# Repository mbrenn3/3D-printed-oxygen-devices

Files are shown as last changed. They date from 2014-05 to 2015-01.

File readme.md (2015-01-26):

This folder contains all the documentation, protocols, data, and manuscript for the 3D printed oxygen devices. 

This will be my first attempt at git tracking a master folder with all the files in one folder.

Inbox
---

- [ ] make a github pages for project to coincide with publication
- [ ] check plos one format and latex outline

todo
====
- [ ] analyze data with imageJ

- [ ] run bubble test

- [ ] well-render with labels and scale bar

- [ ] get megan to write pcr methods, and ask about discussion

- [ ] start new plos template: http://blogs.plos.org/plos/2015/01/streamlined-formatting-plos-article/
sternvolmer6.m

quick plan
--------------

spell check

pandoc for dte

--------
fugutive inks cite
sources for oxygen in intro
fix chemical formating CO2

- [ ] find old data that shows the formation of bubbles

Publication outline
----

Main Goal: demonstrate oxygen control with devices
	mention vacuum flow Vs pressure flow for bubbles

Figure 1: 3D rendering and images of devices
* 3D rendering in Blender
* 24 well device in plate
* petri dish device with lid
* close up membranes
* close up of barbs

Figure 2: Distribution network
* overhead schematic of network
* rendering of overlay and pipe in pipe design 

Figure 3: Oxygen data
24 well device:
* time course data from 21 to 0
* time course data from 0 to 5 to 10 to 21
* final values reached

petri dish: 
* time course from 21 to 0
* time course from 0 to 5 to 10 to 21
* line scan across walls
* difference between the beginning and end of channel

Figure 4: oxygenation schemes with 24 well plate
* data of each row with different oxygen level

Figure 5? bubbles formation?

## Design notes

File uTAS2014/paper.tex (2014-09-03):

\documentclass{article}
\usepackage[utf8]{inputenc}

\title{3D Printed Microfluidic Devices for Oxygen Control in Cell Culture}

\usepackage{natbib}
\usepackage{graphicx}

%\usepackage{fontspec}
%\setmainfont{Times New Roman}

\begin{document}

\maketitle

\section{INTRODUCTION}

3D printing of microfluidic devices enables rapid, one-step fabrication of complex designs infeasible to make with planar lithography and replica molding techniques.
In addition, planar lithography is time consuming, requires specialized equipment and facilities, and has a high failure rate.
On the other hand, 3D CAD printing allows for unambiguous specifications and nearly eliminates time and effort spent on fabrication which is outsourced to a 3D printing company for around \$100/device \cite{Au2014,Chen2014}.
Recently 3D printing has emerged as a method for directly printing complete microfluidic devices (folch, spence, that other one). 
Printing is currently limited in choice of materials when compared to MEMS style fabrication. 
As of yet there is no widely available methods or materials to facilitate direct printing of gas permeable materials.
Here we report on the development of 3D printed microfluidic devices for the control of oxygen in cell culture microenvironments.

\section{EXPERIMENTAL}

The 3” petri dish device contains a 500 $\mu$m wide channel following a serpentine path leaving 500 $\mu$m of spacing between channels and has integrated hose barbs directly printed onto the device.
The 3D part is printed with the channels embedded in the bottom of the petri dish. 
A 120 μm thick PDMS membrane is adhered across the channels.
This device allows cell cluture in a large open well format compatible with assays requireing cell scaping.
The membrane is eaisly peeled away allowing additional fixing/staining assays to be preformed and can also be repaced with a new membrane to reuse the device. 

The 24 well plate insert is designed to control gas in 6 wells of a 24 well culture plate from one input, borrowing the working principle of previous work\cite{Oppegard2010} and also incorporates integrated hose barbs.
The pillars extend into each well leaving a $/sim$500 $\mu$m gap for media between the diffusion membrane and the culutre surface at the bottom of the well.
Diffusion occurs rapidly across this gap allowing control of the dissolved gas environment around the cells. 
This is a prototype intended to be expanded to control all 24 wells.
A distribution network stems from the central input that equalizes the flow along each path length by varying the channel width to the proximal, intermediate, and distal wells.
The device also features a ‘pipe within a pipe’ design so that gas flow enters and leaves the diffusion area in a uniform, and symmetrical flow pattern, which would not be possible with standard lithography and demonstrates the capabilities of 3D printing (Figure \ref{fgr:well-render}.
A PDMS membrane is adhered to the microchannels of both designs by spin coating a thin PDMS layer as an adhesive.

Both devices were printed by Fineline Prototyping in Watershed XC using stereolithography.
Oxygen was measured in the 3” petri dish device with a commercial fiber-optic probe and the 24 well insert was quantified with a planar oxygen sensor as shown in Figure \ref{fig:6-well-photo}.
3D CAD models are designed and printed with microfluidic delivery channels, and then completed by adhering a gas permeable membrane of PDMS (Polydimethylsiloxane) to enable diffusion of gas to the culture area.

\section{RESULTS AND DISCUSSION}

Two devices are presented and characterized: one is a large area (3” diameter) open-well format, and the second is an insert for a standard 24 well plate as shown in Figure \ref{fig:6-well-photo}.

\begin{figure}[h!]
\centering
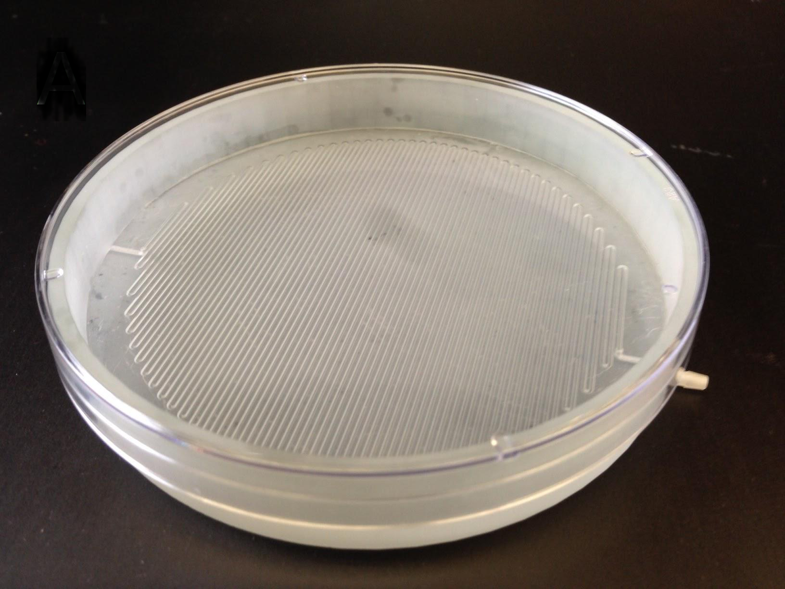
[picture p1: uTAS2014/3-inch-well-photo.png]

\caption{3" petri dish device}
\label{fig:3-inch-well-photo}
\end{figure}

\begin{figure}[h!]
\centering
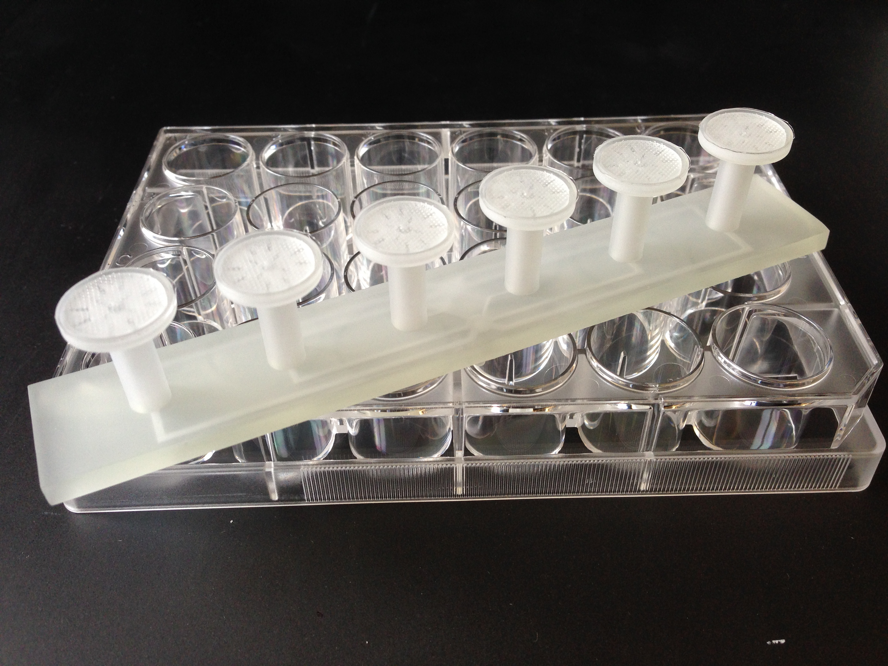
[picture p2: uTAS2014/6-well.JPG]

\caption{6 well device oxygen control device}
\label{fig:6-well-photo}
\end{figure}

\begin{figure}[h!]
\centering
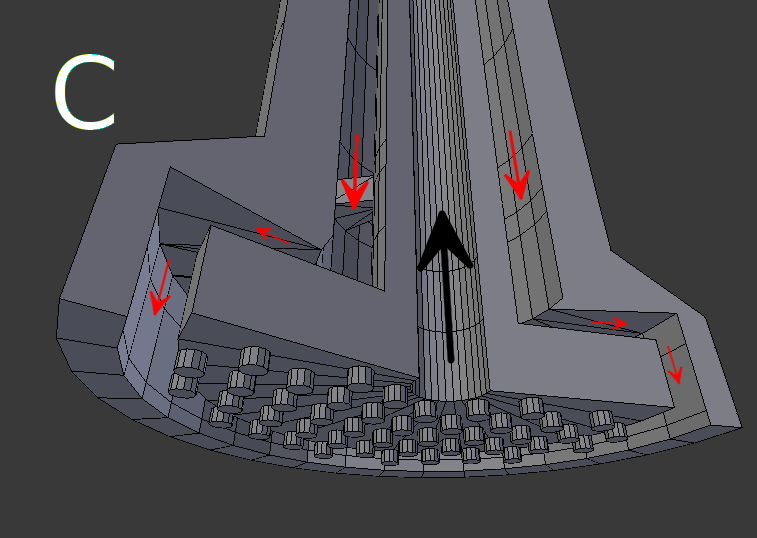
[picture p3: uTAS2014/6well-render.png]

\caption{6 well device oxygen control device}
\label{fig:6well-render}
\end{figure}

\section{CONCLUSION}

3D printing allows complex designs, integrated tubing connectors, and is comparable in price to standard PDMS fabrication.
This technique represents a bridge to commercialization where robust devices can be more easily shared and disseminated.
While injection molding, hot embossing, or other industrial processes are cheaper when making hundreds to thousands of devices, it is not practical to make a injection mold when making tens to hundreds of devices.
In addition, PDMS fabrication would be too time consuming, expensive, and the failure rate would be unacceptable.
3D printing is a perfect solution to these device fabrication needs.

\bibliographystyle{plain}
\bibliography{references}
\end{document}

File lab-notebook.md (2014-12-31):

050714
---

The device is placed in the dish not weighted down

Vacuum was started soon after time point 5 

intensity of well 6 is 354.8 at t5

ran with vacuum only to see if the value remains steady

t6 = 340.272 decrease flow, initally at 30 on rotameter, now at ten. 30 was pulling water into flask rapidly ~20 mL/min. At 10 the there is about 1 drop per second.

t7 = 339.789

t8 = 339.219

t9 = 338.818 

It seems that the flow is causeing the intensity to decrease, most likely through cooling of the sensor. The rotameter is now set to below 5. 

t10 = 338.576

t11 = 338.494 

gas started after t11 - 5% CO2 bal. nitrogen

t12 = 667.168

t13 = 731.666

050814

---

wells 1-5 appear to have no bubbles. 6 has a bubbles that grows during duration, although it seems to be out of the plane of focus, perhaps below the standing well insert or in the device? Perhaps there was a leak and water was pulled into the device? I dont see any water in the device, could have been evaporated as well.

data was logged in to a txt file starting with the exp, then dry calibration, then ss calibration.

New experiment
-----------

same procedure as 050714 

vacuum started after t5. Vacuum rotameter was not touched, it appears to be at the same reading, just under 5. 

well 6 t4 = 366.925

t5 = 365.572

t6 = 363.806

t7 = 362.583

t8 = 361.686

t9 = 361.068

t10 = 360.595

Gas line hooked up after t10 

050914

post calibration taken at 11am 

at 11:15 a aquasition of 30 sec intervals was started after pulling room air rather then %5 CO2 bal. N2. 

intensity data was analyzed and recorded in a txt file intensities050814 starting with SS calibraion, then exp, pulling air

the stage memorization is off. well 1 is 3, 3 was taken twice. 

New Experiment 050914
----
Same procedure as before

calibration was taken with SS then non SS water was replaced and the device placed in without vacuum for first 5 timepoints 

t3 = 374.297
t4 = 373.091
t5 = 371.942

vacuum turned on only pulling air

t6 = 369.925

t7 = 368.804

t8 = 367.961

t9 = 367.043

t10 = 366.204

5% CO2 gas line inserted in to vaccum inlet 

t11 = 700.153

051214
-----

intensity data taken from 050914 place in a .log txt file with SS calibrations fist followed by exp

I dont see any bubbles forming in the images

raw images saved on patriot 

Expirment 051214
------
same procedure as previous days 

t1=373.719

t2=374.277

t3=374.711

t4=374.972

t5=374.874

vacuum turned on pulling room air

t6=372.992

t7=372.034

t8=

t9=371.33

t10=371.006

Gas tubing connceted 

051314
----

intensities logged to .log txt file with SS calibrations first

no bubbles were seen in the images

060514
------
Data was analyzed for days trials 1, 3 and 4 (050714,050914,051214). The second trial was skipped because of the error in stage positions causeing one well to be imaged twice while missing one well. 

The averaged N=3 data looks good.
It is apparent that the distal well do not achieve as much flow or the pillers did not reach close enough to the sensors.
I may try weighing down the device in the plate.

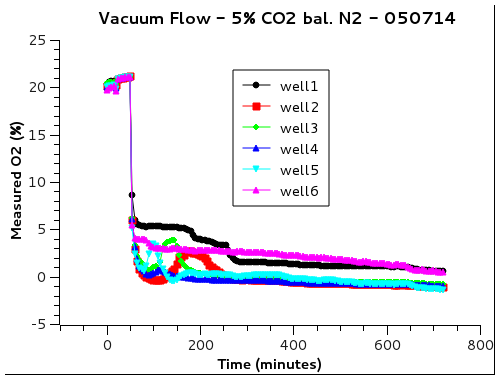
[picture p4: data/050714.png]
trial1

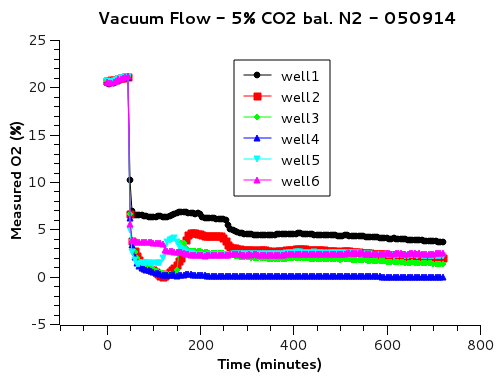
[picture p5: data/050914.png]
trial2

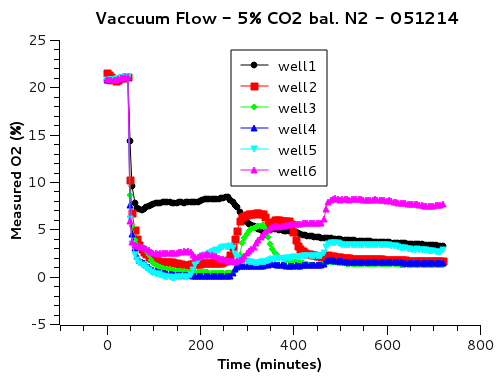
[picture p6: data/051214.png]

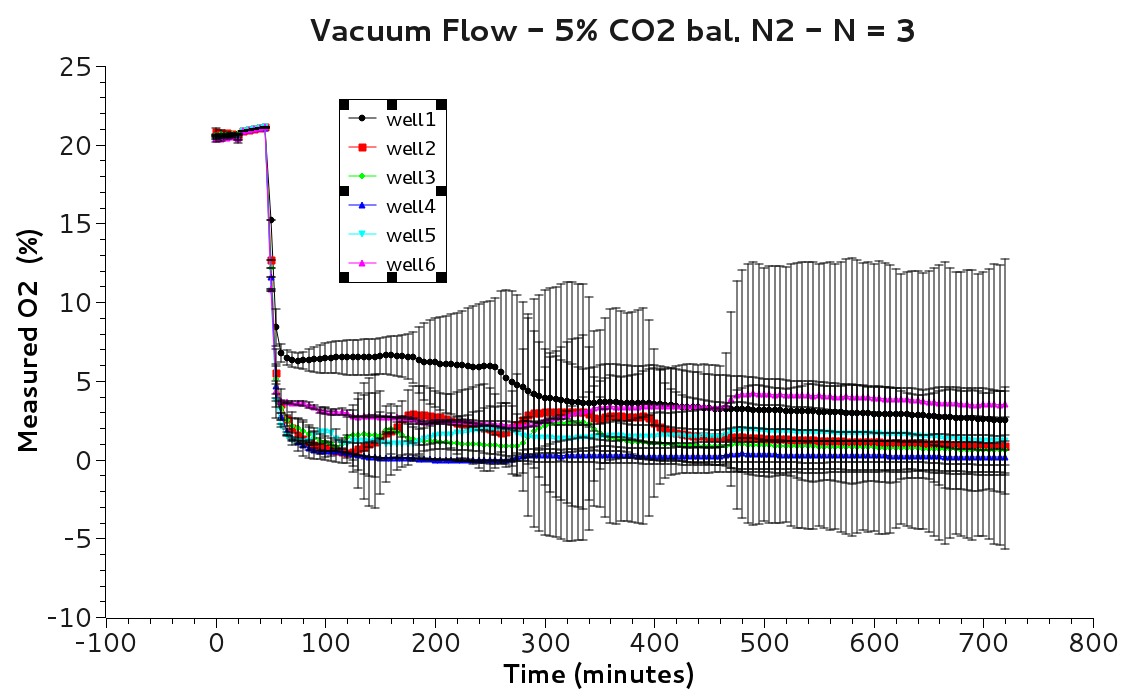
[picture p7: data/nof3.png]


082614
------
experiment with 6 well prototype with manually adjusting the focus

t 17 2261
t 18 2293
t 21 2358
t 22 2372
t 23 2385
t 24 2397

t2 1 2415
t2 3 2433
t2 6 2456
t2 7 2462
t2 11 2481
t2 15 2497
t2 16 2504
t2 19 2510
t2 20 2512
t2 22 2516
t2 24 2525

082714
------
t1 752
t2 740
t4 729
t5 724
t7 720
t8 718
t9 717
t10 716
gas tube placed in 5% CO2 bal. nitrogen no vacuum yet

t11 986
t12 1627
t13 2025
t14 2201
t15 2288
t17 2377

091814
------

Collecting oxygen data the 6 well device
Calibration preformed with SS and with 0% O2 flowing through the device (5% CO2, bal. N2). 
0% O2 gas flowing during calibration to account for temperature changes due to flow and to eliminate O2 difusion from the device to off set calibration point.
vacuum Rotameter: 8
flow rotameter: 27

took nearly 2 hrs for the intensity to stop increasing, calibration images taken and saved in sscal

Calibration for 21% oxygen is preformed after the plate and device are rinsed with DI water and dryed.
Fresh DI water is pipetted into the wells, and air from a compressed air tank is flowed throught the device with vacuum. The vacuum and flow rotameter are set to the same rates. 
intensity steadys around 20 min

z stage was very out of focus the next day. data may be not good

10 points were taken the next day whit z re focused.

I noticed that the weights were not enough to keep the device at the bottom of the wells. One side 1 or 6 side may have been 1mm away from the bottom.

091914
------

New experiment same procedure as 091914. Larger weights this time to keep the device in the bottom of the wells.

092514
------

Started new experiment. 

Noticed water in the tubing and device after calibration with SS. At least 2 pillar were leaking. the device was dehydrated on a hot plate and patched around the membranes with more PDMS. 

100114
------

Experiment with new full plate device.

Took more than an hour for the SS calibration intensity values to steady.
I wonder if the slow action of SS is due to it not being opened in a nitrogen environment.
after the fourth time point the tube was placed in the 5% CO2 bal. N2 tube.

t12 1840.78
t13 1860.99
t14 1877
t15 1890.65
t16 1902.52
t17 1912.58
t18 1921.67
t19 1929
t20 1937
t21 1943
t22 1949.9

t36 2006
t39 2011.15
t40 2013
t46 2026
t48 2029

100314
------

Experiment on the pond scope because the stage works better

I used a fresh batch of SS from within a glove bag flushed with nitrogen. It equalibration still takes over an hour.

100614
------

Second characterization on pond scope

The bulb is not aligned on the pond scope but i plan on taking the region that is bright

The timelapse was set to 60 hour rather than 6

100714
------
Third experiment on the pond scope

no amb calibration stack was taken, tube was placed in one hour in to exp1 MDA

101514
------

0% tube inserted at timepoint 18

120214
------

1st full 24 well characterization

729
722

716

712
710
start 0% O2 in all 4 rows at timepoint 8
t8 1361.18
t13 1715
t18 1780
t19 1720
t20 1661
The regulator needed to be adjusted

22 2049
25 2099
30 2123
31 2127
changed to different conditions

120314
-------

same set up as yesterday

0% started for timepoint 7
9 1837
12 1967
13 1986
16 2032
19 2082
20 2071
22 2089
23 2099
24 2086
25 2095
26 2102
27 2106
gasses set for timepoint 28

I realized that I probably did not rinse the ss off the device for this experiment

120414
-----

same set up as before

723
719
716
713
2022
2041
2065
2083
2089
2093
2096
2099
2084
2103
2107
conditions changed for t 31

120514
------

same set up

t5 723

t8 720
0% applied
t9 1376
t10 1688
t11 1815
t13 1937
t24 1972
t17 2035
t19 2051
t20 2071
24 2098
26 2107
27 2111
2118
conditions changed for t30
2116

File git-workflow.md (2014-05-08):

Git
===

[This](http://git-scm.com/book/en/Getting-Started) book is the best. 

Initial set-up
-------

Start a new folder and cd to it, then check settings:

To list identy and settings
	
	$ git config --list

To set up identitiy: 
	
	$ git config --global user.name "John Doe"
	$ git config --global user.email johndoe@example.com

Initialize a repository, add a readme, a remote, and push to github
--------------------------
You will also have to make the repository on github as well

	$ touch README.md
	$ git init
	$ git add README.md
	$ git commit -m "first commit"
	$ git remote add origin https://github.com/mbrenn3/3D-printed-oxygen-devices.git
	$ git push -u origin master 

Clone an Existing Repository: 
------------------------

	$ git clone https://github.com/mbrenn3/3D-printed-oxygen-devices.git

This will make a directory named 3D-printed-oxygen-devices with the project file inside it.

When you are done working push back to the origin (Github)
----------------------------------

	$ git push -u origin master

Before you start working later pull changes to the local repo
-------------------------------------

	$ git pull origin

What do I do with merging different pushes/pulls?

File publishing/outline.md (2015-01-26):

plan
----
1. get some figures in - then comment out after checking
2. outline text, methods.
3. comment out petri dish device

Intro
===
Planer lithography Vs 3D printing
other 3D printed device papers
no material for oxygen control

Methods
===

Design
------

Figure 1 Devices
---------------------

* CAD render of 3d printed part + membrane + dish
* cad render of whole 24 well part
* photo of whole part
* schematic of distribution network
* render of distribution network

oxygen characterization methods
------

Cell culture and assay methods
-----

Results and Discussion
===

Figure 2 Oxygen Characterization
-----------
* petri dish
  * timcourse to zero
  * linescan - postition data
* 24 well plate
  * timcourse of 24 wells
  * 4 independent conditions

Figure 3 cell stuff with megan
----------
get figures

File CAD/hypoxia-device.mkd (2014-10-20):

#Cancer TPZ Culture Experiments

## Cell models
### mcf-7 
* epithelal like, non-invasive

###mda-mb-231
* fibroblast like, invasive
* Shawn used: Leibovitz’s L-15 media supplemented with 10% fetal bovine serum and 1% penicillin/streptomycin (ATCC)
* More lit about use with TPZ

## Tirapazamine
* reduced to a toxic radical at low oxygen levels
* 5 μM concentration should be a good starting point

## Plan for now:
Culture mda-mb-231's ([Leibovitz’s L-15 media](http://www.fishersci.com/ecomm/servlet/fsproductdetail_10652_11842177__-1_0)(0% CO2), 10% FBS, 1% P/S) in 1, 5, 10 and 21% oxygen with [tirapazamine](http://www.sigmaaldrich.com/catalog/product/sigma/sml0552?lang=en&region=US) at 0, 5, 25, 45, 65, and 100 μM. - go over this with DTE, show other pyrogallol papers.

Culture cells for 6-48 hours under conditions

Use [PrestoBlue](http://products.invitrogen.com/ivgn/product/A13261?ICID=cvc-prestoblue-c1t1) viability assay to determine the relative viability of wells compared to the control wells.

Using Millicell Cell Culture Insert, 12 mm, polycarbonate, 0.4 μm pore size [(PIHP01250)](http://www.millipore.com/catalogue/itemdetail.do?id=PIHP01250) Individually blister packaged

# Device Development

To control the oxygen tension gas must diffuse to the cell culture from the membrane. The time that diffusion will take to deliver(or deplete) oxygen is highly dependent on the distance. A model of the hypoxia device was used to estimate how this distance will effect the efficacy of the device to set up and maintain desired oxygen tensions. 

100% nitrogen was flowed through one pillar of the device started flush against a PtOEPK sensor in several mL of water. The distance between the sensor and the diffusion membrane was increased to 125, 250, 500, 750, 1000, and 1250 um. This was completed three times starting with the diffusion membrane at the sensor and moving up. 

 not sure what this does

# Pyrogallol Characterization

Calibration of the PtOEPK sensors for 0% oxygen was preformed with a sodium sulfite solution of 2 g/L. 
SS

Pyrogallol was flowed through the device rather than gas to create a hypoxic environment at the culture surface. 100 mg of pyrogallol per mL of water was combined with an equal volume of 1 M sodium hydroxide in a nitrogen flushed glovebag. Pyrogallol was flowed through one network/row of 6 wells at 0.25 mL/hr.  
not sure what this does

**the well 5 outlier is most likely due to a bad calibration measurement**

not sure what this does

**Data from above averaged with standard deviation(N=3), well 5 outliler thrown out**

label

**Comparison of tension reached with using gas in the device Vs pyrogallol flowed at 0.25 ml/hr **

## Resazurin/Resorufin
* Resazurin is a non-toxic dye that is reduced in the presence of cell metabolism to resorufin which is highly fluorescent
* fluorescence intensity can be used to quantify live cells - need to work through protocol for this
* [569/586](http://www.fluorophores.tugraz.at/substance/45) excitation/emmission
	* should be compatable with [TRITC](http://www.thorlabs.com/images/TabImages/MDF-TRITC_Resorufin.jpg), [Texas Red](http://www.thorlabs.com/images/TabImages/MDF-TXRED_Resorufin.jpg) or [CY3.5](http://www.thorlabs.com/images/TabImages/MDF-Cy3.5_Resorufin.jpg) filter cube
* commerical varites: [AlamarBlue](http://products.invitrogen.com/ivgn/product/DAL1025), [PrestoBlue](http://products.invitrogen.com/ivgn/product/A13261?ICID=cvc-prestoblue-c1t1)
* use a no-cell control well for correcting background fluorescence, as well as an untreated cells control
* add 1/9th volume of cells + media to each well, so for 24 well plate with 1.8 mL volume add 200 um of PrestoBlue

### Working protocol for resazurin/resorufin with microscope

A plate-reader may not be ideal for this experiment because the desired condition to be tested will only be at the insert membrane. Althought TPZ will be throughout the well the desired oxygen tension will only be applied to cells on the insert membrane. Cells in different areas of the well will not be effected by the TPZ-hypoxia condition and may skew the over all fluorescence.

The resazurin/resorufin must be calibrated to correlate number of cells to fluorescence. A cell count must be preformed with hemocytometer on a control well. This must also be adjusted to surface area because the microscope can't image the entire well.

Perhaps to avoid cell count and surface area issues the viablily (overall fluorescence) can just be normalized to a control well.

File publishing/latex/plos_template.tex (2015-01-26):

% Template for PLoS
% Version 2.0 July 2014
%
% To compile to pdf, run:
% latex plos.template
% bibtex plos.template
% latex plos.template
% latex plos.template
% dvipdf plos.template
%
% % % % % % % % % % % % % % % % % % % % % %
%
% -- IMPORTANT NOTE
%
% Be advised that this is merely a template 
% designed to facilitate accurate translation of manuscript content 
% into our production files. 
%
% This template contains extensive comments intended 
% to minimize problems and delays during our production 
% process. Please follow the template 
% whenever possible.
%
% % % % % % % % % % % % % % % % % % % % % % % 
%
% Once your paper is accepted for publication and enters production, 
% PLEASE REMOVE ALL TRACKED CHANGES in this file and leave only
% the final text of your manuscript.
%
% DO NOT ADD EXTRA PACKAGES TO THIS TEMPLATE unless absolutely necessary.
% Packages included in this template are intentionally
% limited and basic in order to reduce the possibility
% of issues during our production process.
%
% % % % % % % % % % % % % % % % % % % % % % %
%
% -- FIGURES AND TABLES
%
% DO NOT INCLUDE GRAPHICS IN YOUR MANUSCRIPT
% - Figures should be uploaded separately from your manuscript file. 
% - Figures generated using LaTeX should be extracted and removed from the PDF before submission. 
% - Figures containing multiple panels/subfigures must be combined into one image file before submission.
% See http://www.plosone.org/static/figureGuidelines for PLOS figure guidelines.
%
% Tables should be cell-based and may not contain:
% - tabs/spacing/line breaks within cells to alter layout
% - vertically-merged cells (no tabular environments within tabular environments, do not use \multirow)
% - colors, shading, or graphic objects
% See http://www.plosone.org/static/figureGuidelines#tables for table guidelines.
%
% For sideways tables, use the {rotating} package and use \begin{sidewaystable} instead of \begin{table} in the appropriate section. PLOS guidelines do not accomodate sideways figures.
%
% % % % % % % % % % % % % % % % % % % % % % % %
%
% -- EQUATIONS, MATH SYMBOLS, SUBSCRIPTS, AND SUPERSCRIPTS
%
% IMPORTANT
% Below are a few tips to help format your equations and other special characters according to our specifications. For more tips to help reduce the possibility of formatting errors during conversion, please see our LaTeX guidelines at http://www.plosone.org/static/latexGuidelines
%
% Please be sure to include all portions of an equation in the math environment, and for any superscripts or subscripts also include the base number/text. For example, use $mathrm{mm}^2$ instead of mm$^2$ (do not use \textsuperscript command).
%
% DO NOT USE the \rm command to render mathmode characters in roman font, instead use $\mathrm{}$
% For bolding characters in mathmode, please use $\mathbf{}$ 
%
% Please add line breaks to long equations when possible in order to fit our 2-column layout. 
%
% For inline equations, please do not include punctuation within the math environment unless this is part of the equation.
%
% For spaces within the math environment please use the \; or \: commands, even within \text{} (do not use smaller spacing as this does not convert well).
%
%
% % % % % % % % % % % % % % % % % % % % % % % %

\documentclass[10pt]{article}

% amsmath package, useful for mathematical formulas
\usepackage{amsmath}
% amssymb package, useful for mathematical symbols
\usepackage{amssymb}

% cite package, to clean up citations in the main text. Do not remove.
\usepackage{cite}

\usepackage{hyperref}

% line numbers
\usepackage{lineno}

% ligatures disabled
\usepackage{microtype}
\DisableLigatures[f]{encoding = *, family = * }

% rotating package for sideways tables
%\usepackage{rotating}

% If you wish to include algorithms, please use one of the packages below. Also, please see the algorithm section of our LaTeX guidelines (http://www.plosone.org/static/latexGuidelines) for important information about required formatting.
%\usepackage{algorithmic}
%\usepackage{algorithmicx}

% Use doublespacing - comment out for single spacing
%\usepackage{setspace} 
%\doublespacing

% Text layout
\topmargin 0.0cm
\oddsidemargin 0.5cm
\evensidemargin 0.5cm
\textwidth 16cm 
\textheight 21cm

% Bold the 'Figure #' in the caption and separate it with a period
% Captions will be left justified
\usepackage[labelfont=bf,labelsep=period,justification=raggedright]{caption}

% Use the PLoS provided BiBTeX style
\bibliographystyle{plos2009}

% Remove brackets from numbering in List of References
\makeatletter
\renewcommand{\@biblabel}[1]{\quad#1.}
\makeatother

% Leave date blank
\date{}

\pagestyle{myheadings}

%% Include all macros below. Please limit the use of macros.

%% END MACROS SECTION

\begin{document}

% Title must be 150 characters or less
\begin{flushleft}
{\Large
\textbf{3D-Printed Oxygen Control Devices}
}
% Insert Author names, affiliations and corresponding author email.
\\
Martin D. Brennan$^{1}$, 
Megan L. Rexius-Hall$^{1}$, 
David T. Eddington$^{1,\ast}$
\\
\bf{1} Dept of Bioengineering, University of Illinois at Chicago, Chicago, Illinois, USA
\\
%\bf{2} Author2 Dept/Program/Center, Institution Name, City, State, Country
%\\
%\bf{3} Author3 Dept/Program/Center, Institution Name, City, State, Country
%\\
$\ast$ E-mail: Corresponding dte@uic.edu
\end{flushleft}

% Please keep the abstract between 250 and 300 words
\section*{Abstract}

Recently 3D printing has emerged as a method for directly printing complete microfluidic chips, 
although printing materials have been limited to non-oxygen permeable materials.
We demonstrate the addition of gas permeable PDMS (Polydimethylsiloxane) membranes to 3D printed microfluidic devices as a means to enable oxygen control cell culture studies.
%Two devices are presented and characterized.

% Please keep the Author Summary between 150 and 200 words
% Use first person. PLOS ONE authors please skip this step. 
% Author Summary not valid for PLOS ONE submissions.   
\section*{Author Summary}

\section*{Introduction}

3D printing of microfluidic devices enables rapid, one-step fabrication of complex designs infeasible to make with planar lithography and replica molding techniques.
In addition, planar lithography is time consuming, requires specialized equipment and facilities, and has a high failure rate.
It is not unusual for labs to make ten microfluidic devices to guarantee one will work properly.
On the other hand, 3D CAD printing allows for unambiguous specifications and nearly eliminates time and effort spent on fabrication which is outsourced to a 3D printing company for around \$100/device \cite{Au2014,Chen2014}.
3D printing also allows integration of complex geometries not possible with planar lithography, such as hose barbs and luer fittings.
Dissemination and distributed production is also vastly simplified due to easy sharing the design as a CAD file.
Due to these inherent advantages 3D printing has emerged as a method for directly printing complete microfluidic devices \cite{Au2014, Chen2014, Shallan2014,Erkal2014,Kitson2014}. 
Printing is currently limited in choice of materials when compared to MEMS style fabrication. 
As of yet there is no widely available methods or materials to facilitate direct printing of gas permeable materials.

Microfluidic cell culture devices are often made out of PDMS via soft photo lithography.
PDMS is a convenient material for cell studies due to it's biocompatibility, optical properties, and gas permeability, facilitating oxygen control of cell environments.

Oxygen control in cells studies is often overlooked by researchers, but important for mimicking conditions experienced by cells in vivo.
Typically cell culture studies are preformed at 21\% oxygen, atmospheric oxygen conditions, although levels that cells experience in vivo are usually less.
For example tumors, in general, are hypoxic as they rapidly out grow their vasculature creating a hypoxic inner region. 
To better study the role of oxygen levels in cancer gene expression a gas controlled culture system is required.

Oxygen control mulitwell inserts have been previously developed, which were cast entirely from PDMS, for 6 well culture plates. \cite{Oppegard2009, Oppegard2010}.
To replicate the 6-well design for a 24 well format the fabrication via PDMS casting becomes too tedious and to be done by hand and has a high failure rate.
Utilizing 3D printing for the fabrication allowed further features to be incorporated such as integrated distribution channels and hose barbs, while eliminating fabrication time and failure rate.
Although available 3D printable materials are non-gas-permeable, the addition of a PDMS membrane allows gas transfer. 
In this case, having a non-gas-permeable material for the bulk is advantageous as it acts as a insulator to gas transfer. 
Convection and distribution of the gas is done in the non-permeable material eliminating dilution of the gas before reaching the diffusion layer. 
The previous PDMS devices were parylene coated along the convection channels to eliminate exchange of gas from the PDMS bulk. 

---Motovation for oxygen control, what we have done previously in oxygen and sepcificly the 6-well plate and why we need to do this with a 3D printer. Also a bit on negative pressure Vs. positive pressure. - I don't have any data or any reason that I can prove for doing this. I was orginally afraid that the membranes would come off from the pressure, I am testing it now.---

Here we report on the development of 3D printed microfluidic devices for the control of oxygen in cell culture microenvironments.
We demonstrate a device that nests into a 24 well culture plate to control gas in each row of the plate independently of the incubator's condition.

% You may title this section "Methods" or "Models". 
% "Models" is not a valid title for PLoS ONE authors. However, PLoS ONE
% authors may use "Analysis" 
\section*{Materials and Methods}

%The 3-inch (75 mm) petri dish device contains a 500 $\mu$m wide channel following a serpentine path leaving 500 $\mu$m of spacing between channels and has integrated hose barbs directly printed onto the device.
%The 3D part is printed with the channels embedded in the bottom of the petri dish. 
%A 120 $\mu$m thick PDMS membrane is adhered across the channels by spin coating a thin layer of PDMS on the membrane and allowing it to cure in place.
%The device is designed so that a standard 3” petri dish lid may be used.
%This device allows cell culture in a large open well format compatible with assays requiring cell scraping.
%The membrane is easily peeled away allowing additional fixing/staining assays to be preformed and can also be replaced with a new membrane to reuse the device. 

\subsection*{Design of Insert}

The device was designed to integrate with a multiwell format, specifically an off-the-shelf 24 well plate. 
The 24 well plate insert is designed to control gas in 6 wells of a 24 well culture plate from one input, borrowing the working principle of previous work\cite{oppegard2010} and also incorporates an integrated distribution network and hose barbs to simplify device operation.
The pillars extend into each well leaving a $\sim$500 $\mu$m gap for media between the diffusion membrane and the culture surface at the bottom of the well.
Diffusion occurs rapidly across this gap allowing control of the dissolved gas environment around the cells. 
A distribution network stems from the central input that equalizes the flow along each path length by varying the channel width to the proximal, intermediate, and distal wells (Figure \ref{figure1}.

The device also features a ‘pipe within a pipe’ design so that gas flow enters and leaves the diffusion area in a uniform, and symmetrical flow pattern, which would not be possible with standard lithography and demonstrates the capabilities of 3D printing (Figure \ref{figure1}.
Again the membranes are adhered with a thin layer of PDMS on the membrane and allowed to cure in place.

The device was printed by Fineline Prototyping in Watershed XC using stereolithography.
CAD models were designed and printed with microfluidic delivery channels, and then completed by 
adhering a gas permeable membrane of PDMS to enable diffusion of gas to the culture area. 

\subsection*{Oxygen characterization}

Oxygen was measured with PtOEPK (Pt(II) Octaethylporphine ketone) planar sensors that were fixed to the bottom of a 24 well plate. 
The intensity of the sensor was measured and correlated to the concentration of oxygen with Stern-Volmer analysis (Figure \ref{piller-well-render-figure}.
Gas was perfused through the device with negative pressure to eliminate bubbles.
The inlet tubing was placed in a cone with with a flow that exceed the vacuum flow rate so that the vacuum was always pulling in the gas of interest and not the room air.
All gas tanks used in the oxygen characterization were 5\% CO2 in addition to the desired gas mix in anticipation of cell culture experiments as CO2 can alter the fluorescence of the PtOEPK.

\subsection*{Cell culture and hypoxia assay}

% Results and Discussion can be combined.
\section*{Results and Discussion}

%Oxygen was measured in the 3” petri dish device with a commercial fiber­optic probe (Figure 2).
%Oxygen control was demonstrated with gas flowing through the channel under the PDMS membrane.

The 24 well insert device was quantified with a platinum based (PtOEPK) planar oxygen sensor as shown in Figure \ref{oxygen-char-figure}.
Oxygen control was able to be controlled in each of the 6 wells equally from one gas input demonstrating the distribution network.
The device reaches steady state in 30 minutes and can then hold the oxygen level near 0\% indefinitely, while 100\% nitrogen is pumped through the device. 
\bf{reach different levels.}

% We only support three levels of headings, please do not create a heading level below \subsubsection.
\subsection*{Subsection 1}

\subsubsection*{SubSubsection 1.1}

\subsection*{Subsection 2}

%\section*{Discussion}

\section*{Conclusion}
3D printing microfluidic chips have been limited to non oxygen permeable materials.
We demonstrate oxygen control in 3D printed devices the addition of a gas permeable PDMS membrane. 
Oxygen control is demonstrated in a open well petri dish design and a 24 well plate.
3D printing allows complex designs, integrated tubing connectors, and is comparable in price to standard PDMS fabrication.
This technique represents a bridge to commercialization where robust devices can be more easily shared and disseminated.
While injection molding, hot embossing, or other industrial processes are cheaper when making hundreds to thousands of devices, it is not practical to make a injection mold when making tens to hundreds of devices.
In addition, PDMS fabrication would be too time consuming, expensive, and the failure rate would be unacceptable.
3D printing is a perfect solution to these device fabrication needs.

% Do NOT remove this, even if you are not including acknowledgments.

\section*{Acknowledgments}

This work funded by NSF 1253060.

%\section*{References}

\bibliography{references}

% Either type in your references using
% \begin{thebibliography}{}
% \bibitem{}
% Text
% \end{thebibliography}
%
% OR
%
% Compile your BiBTeX database using our plos2009.bst
% style file and paste the contents of your .bbl file
% here.
% 

\section*{Figure Legends}
% This section is for figure legends only, do not include
% graphics in your manuscript file.
%
%\begin{figure}
%\caption{
%{\bf Bold the first sentence.}  Rest of figure caption.  
%}
%\label{Figure_label}
%\end{figure}

% copy and paste for figures
%\begin{figure}
%\includegraphics[scale=0.2]{image.jpg} % remove for manuscript submission
%\caption{
%{\bf Bold the first sentence.}  Rest of figure caption.  
%}
%\label{Figure_label}
%\end{figure}

\begin{figure}
%\includegraphics[scale=0.2]{../presentation-figures/piller-well-render-with-arrows.png} % remove for manuscript submission
\caption{
{\bf CAD rendering of the piller bottom.} The 'Pipe with in a pipe' flow pattern delivers gas to the bottom of each well where it diffuses to the culture.  
}
\label{piller-well-render-figure}
\end{figure}

\begin{figure}
%\includegraphics[scale=0.05]{../presentation-figures/24well.JPG} % remove for manuscript submission
%\includegraphics[scale=0.05]{../presentation-figures/printed-network.JPG} % remove for manuscript submission
\caption{
{\bf Photographs of the printed device.}  The printed device with membranes adhered. The distribution network is printed completely in resin.
}
\label{device-photos-figure}
\end{figure}

\begin{figure}
%\includegraphics[scale=0.3]{../presentation-figures/6-well-plot.png} % remove for manuscript submission
%\includegraphics[scale=0.3]{../presentation-figures/24-well-plot.png} % remove for manuscript submission
\caption{
{\bf Oxygen Characterization.}  Time course data of oxygen being evacuated from the culture area as 0\% oxygen gas is perfused through the device. Each 6 well row of the plate can be controlled independently.  
}
\label{oxygen-char-figure}
\end{figure}

\begin{figure}
%\includegraphics[scale=0.2]{image.jpg} % remove for manuscript submission
\caption{
{\bf PCR Data.}  Not finished yet.  
}
\label{pcr-data}
\end{figure}

\section*{Tables}
% 
% See introductory notes if you wish to include sideways tables.
%
% NOTE: Please look over our table guidelines at http://www.plosone.org/static/figureGuidelines#tables to make sure that your tables meet our requirements. Certain types of spacing, cell merging, and other formatting tricks may have unintended results and will be returned for revision.
%
%\begin{table}[!ht]
%\caption{
%\bf{Table title}}
%\begin{tabular}{|c|c|c|}
%table information
%\end{tabular}
%\begin{flushleft}Table caption
%\end{flushleft}
%\label{tab:label}
% \end{table}

\section*{Supporting Information Legends}
%
% Please enter your Supporting Information captions below in the following format:
%\item{\bf Figure SX. Enter mandatory title here.} Enter optional descriptive information here.
% 
%\begin{description}
%\item {\bf}
%\item {\bf}
%\end{description}

\end{document}

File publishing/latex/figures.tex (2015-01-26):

\documentclass[]{article}

\usepackage{graphicx}

%opening
\title{Figures for  3-D printed oxygen devices}
\author{}

\begin{document}

%\maketitle

\section{figures}

\begin{figure}[H]
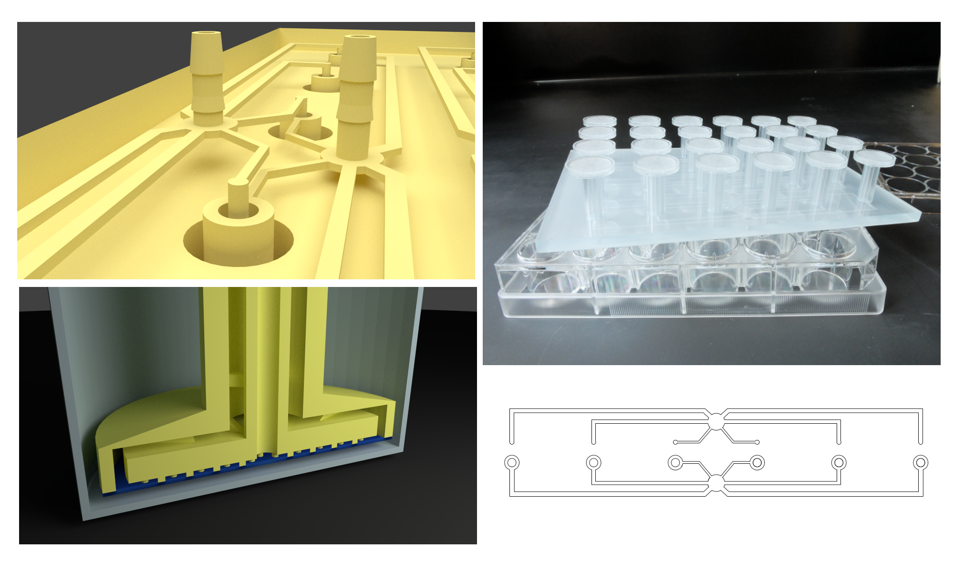
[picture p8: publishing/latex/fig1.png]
 
\caption{
{\bf 24-well Insert Device.} A microfluidic network distributes gas flow from one hose barb input to 6 wells.
A 'Pipe with in a pipe' design delivers gas to the bottom of each well where it diffuses to the culture through an adhered PDMS membrane (blue-layer).  
The distribution network width of the channels in the distribution network are such that the flow rates are equalized to each well dependent on the path length.
}
\label{figure1}
\end{figure}

\begin{figure}[H]
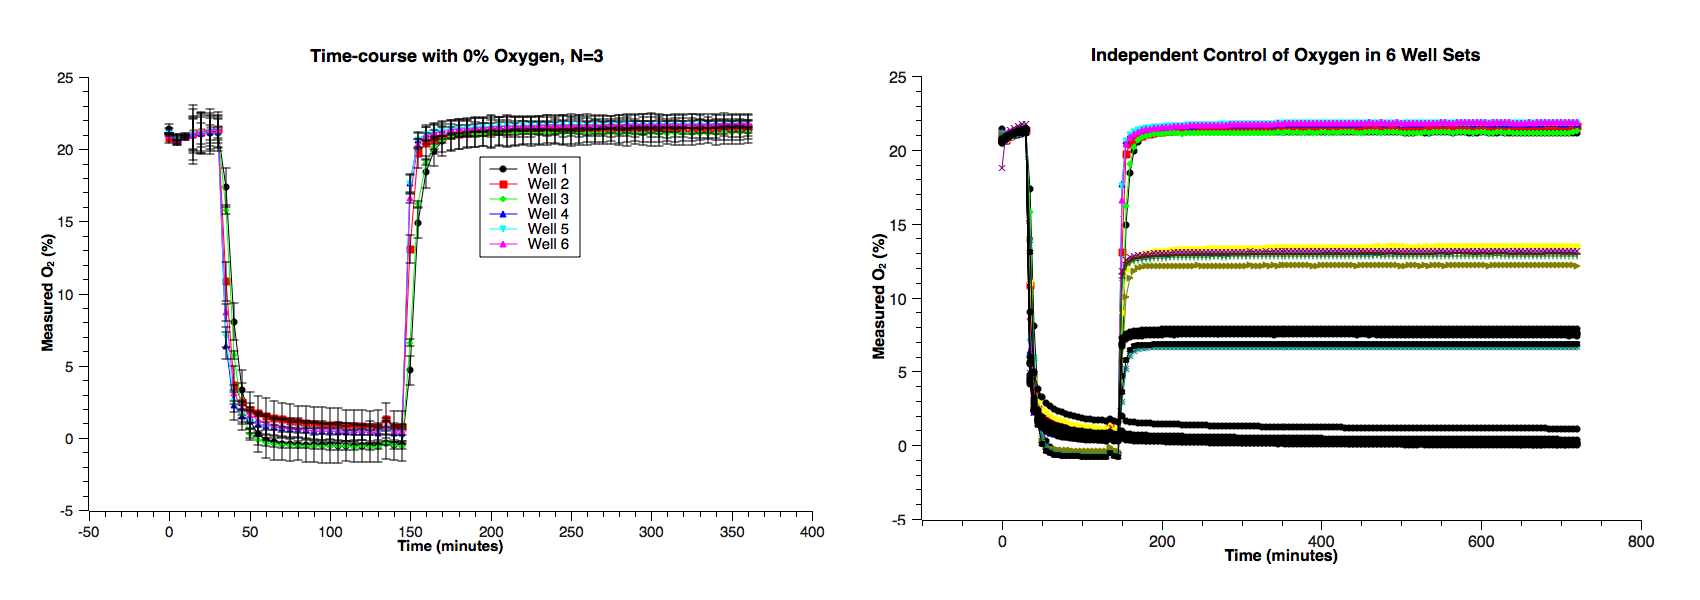
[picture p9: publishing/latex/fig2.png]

\caption{
{\bf Oxygen Characterization.}  Time course data of oxygen being evacuated from the culture area as 0\% oxygen gas is perfused through the device. Each 6 well row of the plate can be controlled independently.  
}
\label{figure2}
\end{figure}

\begin{figure}[H]
%\includegraphics[scale=0.2]{image.jpg} % remove for manuscript submission
\caption{
{\bf PCR Data.}  Not finished yet.  
}
\label{pcr-data}
\end{figure}

%\begin{abstract}

%\end{abstract}

%\section{}

\end{document}

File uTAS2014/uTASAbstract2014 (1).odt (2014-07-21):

Topic No. 2.01 Abstract Reference No: 0023

Oral or Poster

3D PRINTED MICROFLUIDIC DEVICES FOR OXYGEN CONTROL IN CELL CULTURE

Martin D Brennan* and David T Eddington*

*University of Illinois at Chicago - Dept. of Bioengineering, 820 S. Wood St., Chicago, IL 60612

3D printing of microfluidic devices enables rapid, one-step fabrication of complex designs infeasible to make with planar lithography and replica molding techniques. In addition, planar lithography is time consuming, requires specialized equipment and facilities, and has a high failure rate. On the other hand, 3D CAD printing allows for unambiguous specifications and nearly eliminates time and effort spent on fabrication which is outsourced to a 3D printing company for around $100/device [1,2]. Here we report on the development of 3D printed microfluidic devices for the control of oxygen in cell culture microenvironments. 3D CAD models are designed and printed with microfluidic delivery channels, and then completed by adhering a gas permeable membrane of PDMS (Polydimethylsiloxane) to enable diffusion of gas to the culture area. Two devices are presented and characterized: one is a large area (3” diameter) open-well format, and the second is an insert for a standard 24 well plate as shown in Figure 1.

The 3” petri dish device contains a 500 μm wide channel following a serpentine path leaving 500 um of spacing between channels and has integrated hose barbs directly printed onto the device. The 24 well plate insert is designed to control gas in 6 wells of a 24 well culture plate from one input, borrowing the working principle of previous work and also incorporates integrated hose barbs [3]. This is a prototype intended to be expanded to control all 24 wells. A distribution network stems from the central input that equalizes the flow along each path length by varying the channel width to the proximal, intermediate, and distal wells. The device also features a ‘pipe within a pipe’ design so that gas flow enters and leaves the diffusion area in a uniform, and symmetrical flow pattern, which would not be possible with standard lithography and demonstrates the capabilities of 3D printing. A PDMS membrane is adhered to the microchannels of both designs by spin coating a thin PDMS membrane and using PDMS as an adhesive. Both devices were printed by Fineline Prototyping in Watershed XC using stereolithography. Oxygen was measured in the 3” petri dish device with a commercial fiber-optic probe and the 24 well insert was quantified with a planar oxygen sensor as shown in Figure 2.

3D printing allows complex designs, integrated tubing connectors, and is comparable in price to standard PDMS fabrication. This technique represents a bridge to commercialization where robust devices can be more easily shared and disseminated. While injection molding, hot embossing, or other industrial processes are cheaper when making hundreds to thousands of devices, it is not practical to make a injection mold when making tens to hundreds of devices. In addition, PDMS fabrication would be too time consuming, expensive, and the failure rate would be unacceptable. 3D printing is a perfect solution to these device fabrication needs.

Word count: 469

Figure 1: 3D printed devices. (A) 3” petri dish device. (B) 6 well prototype of 24 well plate insert. (C) Cross sectional CAD rendering of ‘pipe in pipe’ design. Red arrows indicate flow to the diffusion chamber and the black arrow is exhausted gas.

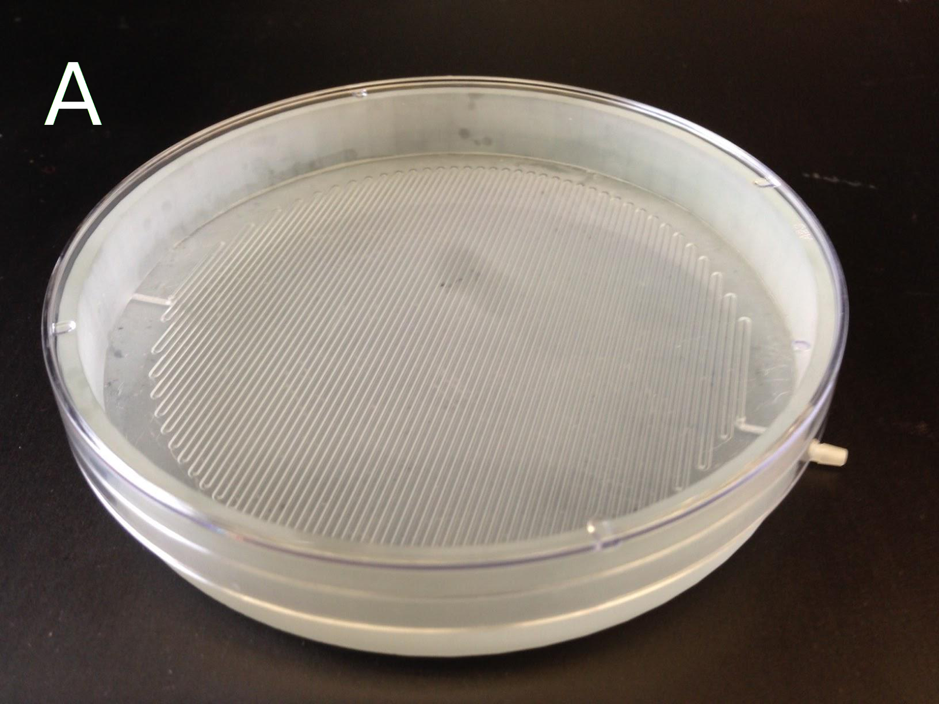
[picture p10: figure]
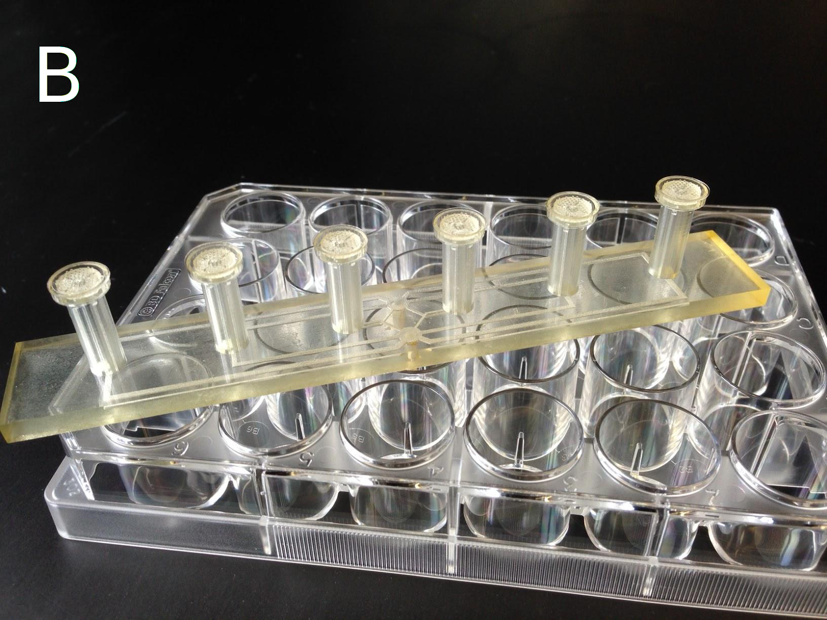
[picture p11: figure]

Figure 2: Preliminary oxygen characterization data. (Left) Oxygen control in the open well petri dish device measured with a commercially available fiber optic oxygen probe. Error bars are the standard deviation, N=3. (Right) Oxygen control in 6 wells of a 24 well plate from a single gas input. Intensity measurements were taken from a platinum(II) octaethylporphyrinketone planar sensor spaced 500 μm away in a standing well insert and analyzed with the Stern-Volmer relationship.

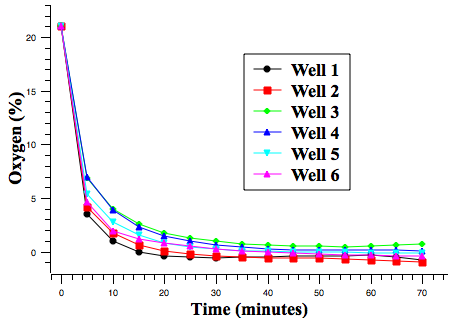
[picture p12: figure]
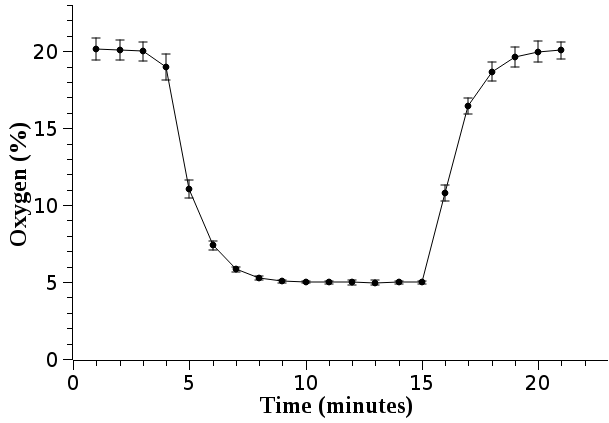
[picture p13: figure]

References:

[1] Anthony K Au, Wonjae Lee, and Albert Folch. Mail-order microfluidics: evaluation of stereolithography for the production of microfluidic devices. Lab on a chip, 14(7):1294–301, March 2014.

[2] Chengpeng Chen, Yimeng Wang, Sarah Y Lockwood, and Dana M Spence. 3D-printed fluidic devices enable quantitative evaluation of blood components in modified storage solutions for use in transfusion medicine. The Analyst, March 2014.

[3] Shawn C Oppegard, Alexander J Blake, Justin C Williams, and David T Eddington. Precise control over the oxygen conditions within the Boyden chamber using a microfabricated insert. Lab on a chip, 10(18):2366–73, September 2010.

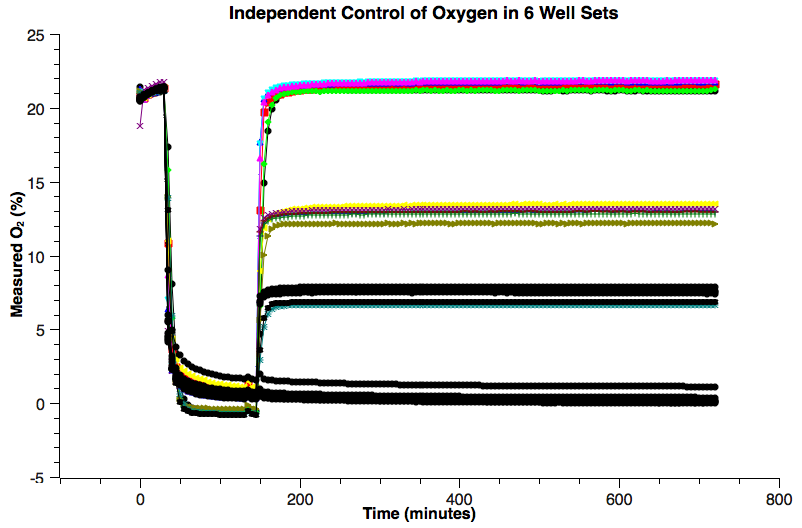
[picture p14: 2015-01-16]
publishing/figures/24-well-plot.png

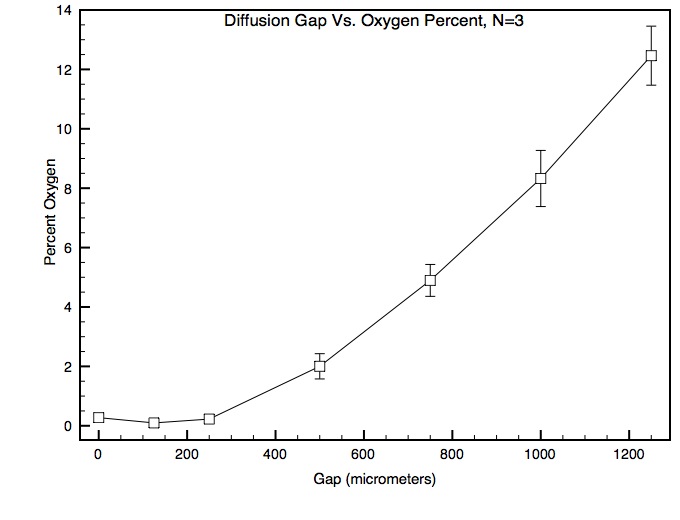
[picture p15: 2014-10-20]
publishing/figures/diffgap.jpg

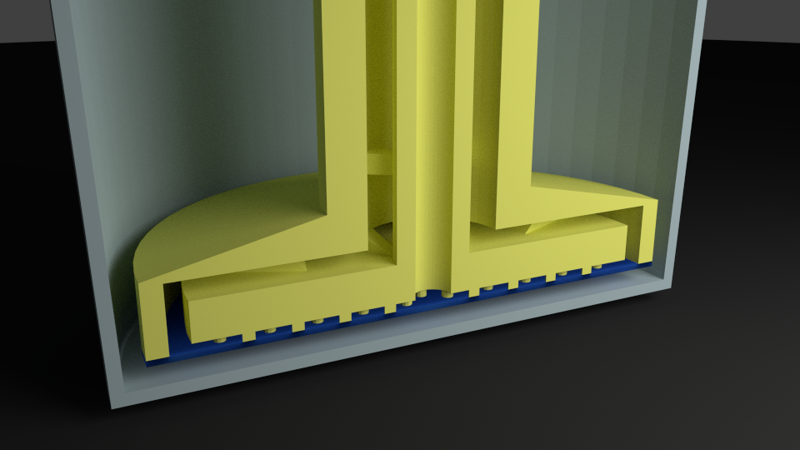
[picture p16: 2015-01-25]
publishing/figures/piller-well-render.png

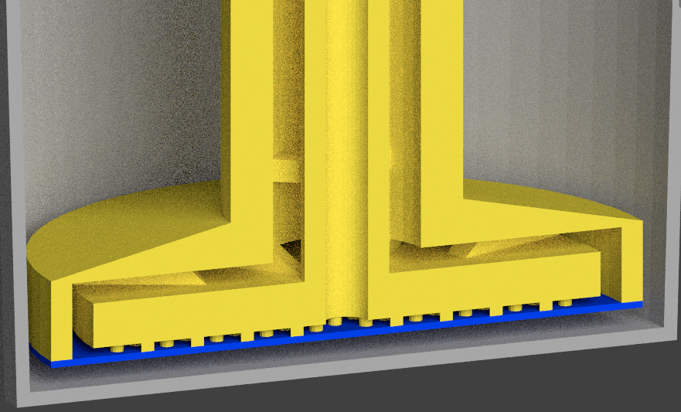
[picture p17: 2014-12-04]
publishing/figures/piller-well-render.tiff

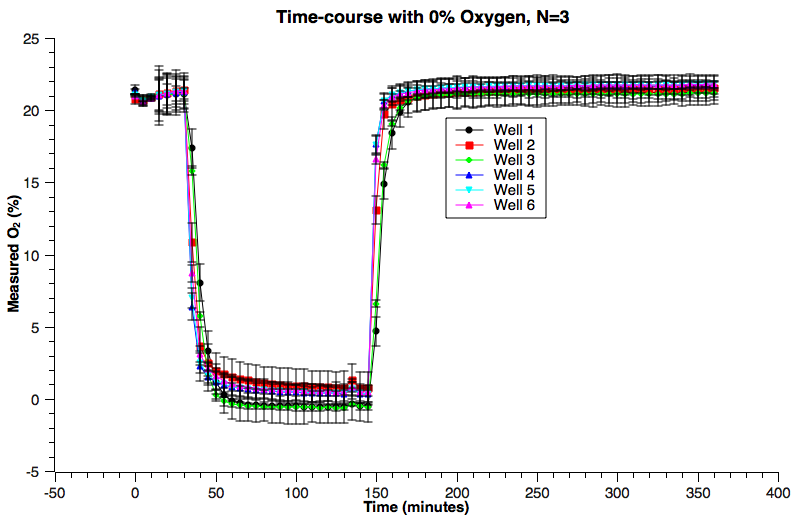
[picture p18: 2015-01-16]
publishing/figures/6-well-plot.png

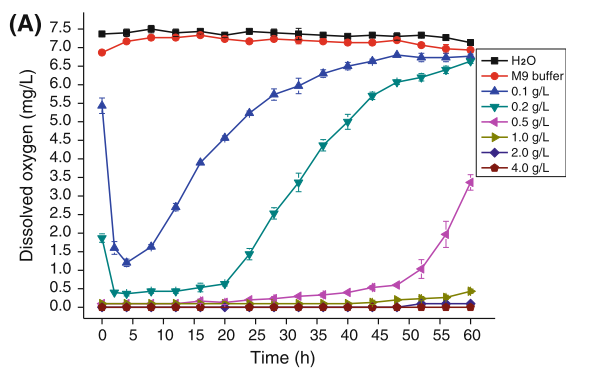
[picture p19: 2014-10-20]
publishing/figures/SScurve.png

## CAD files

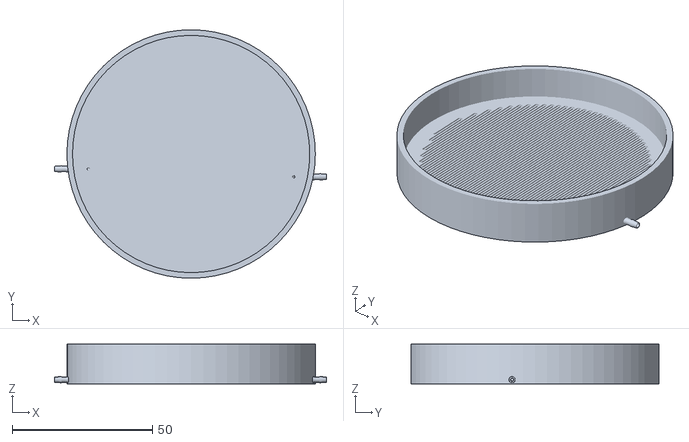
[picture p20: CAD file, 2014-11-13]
CAD/open-well-petri.stl
96.9 x 88.5 x 14.2

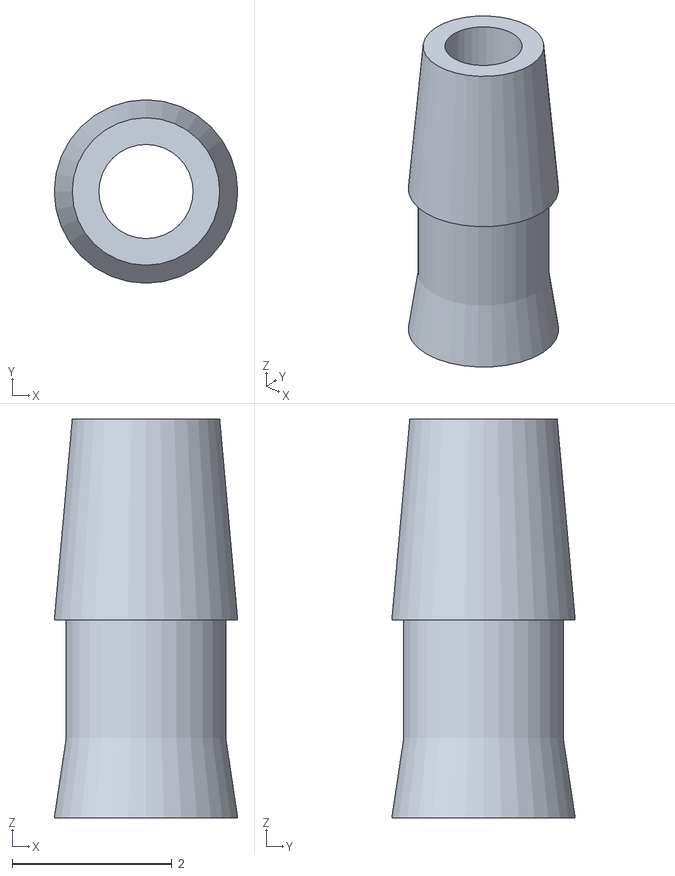
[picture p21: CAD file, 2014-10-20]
CAD/barb.stl
2.30 x 2.30 x 5.00

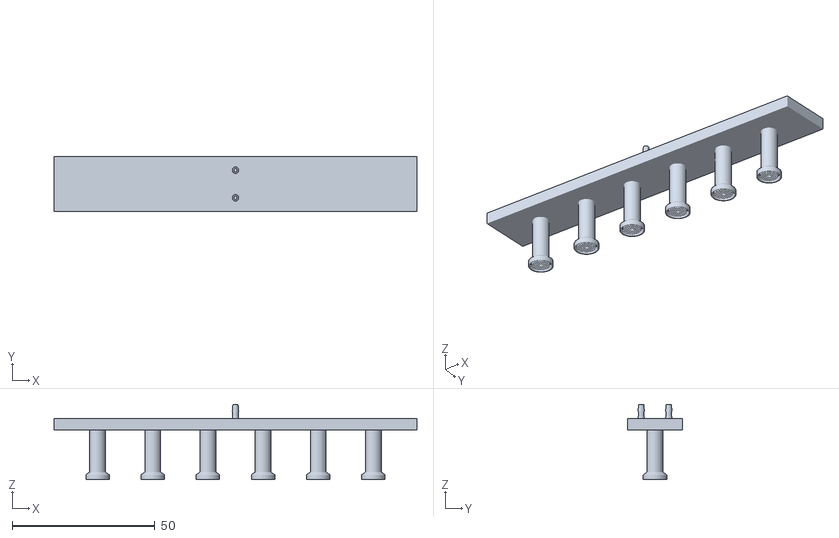
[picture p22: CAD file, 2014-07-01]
CAD/6-well.stl
127.0 x 19.3 x 26.3

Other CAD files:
CAD/2D-network-render-aligned.dwg
CAD/2D-network-render.dwg
CAD/2D-network-render-seperated.dwg
CAD/2D-network.dwg
CAD/2d-distro-template.dwg
CAD/multiembryo.stl
CAD/membrane-cut-template.dwg
CAD/6-well-insert.stl
CAD/24-well-render-well.blend
CAD/6-well-insert.blend
CAD/6-well.blend
CAD/open-well-petri.blend
publishing/figures/pillar-well.blend

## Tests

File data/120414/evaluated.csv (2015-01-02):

# |  | Created | by | Octave | 3.6.2 |  | Fri | Jan | 2 | 15:44:07 | 2015 | CST | <martin@martin-bml>
# |  | name: | a
# |  | type: | matrix
# |  | rows: | 149
# |  | columns: | 24
 |  | 0 | 0 | 0 | 0 | 0 | 0 | 0 | 0 | 0 | 0 | 0 | 0 | 0 | 0 | 0 | 0 | 0 | 0 | 0 | 0 | 0 | 0 | 0 | 0
 |  | Inf | Inf | Inf | Inf | Inf | Inf | Inf | Inf | Inf | Inf | Inf | Inf | Inf | Inf | Inf | Inf | Inf | Inf | Inf | Inf | Inf | Inf | Inf | Inf
 |  | 21 | 21 | 21 | 21 | 21 | 21 | 21 | 21 | 21 | 21 | 21 | 21 | 21 | 21 | 21 | 21 | 21 | 21 | 21 | 21 | 21 | 21 | 21 | 21
 |  | 1120.7969921986 | 1079.9688767363 | 1085.5330490391 | 1062.5588973784 | 1116.7524599941 | 1057.1116398448 | 1074.5947127581 | 1106.3845444204 | 1053.6265152569 | 1098.6377388995 | 1054.6545309972 | 1071.0968607747 | 1156.5078066201 | 1116.3647743195 | 1089.8662994806 | 1086.1706414049 | 1107.6661564523 | 1036.7415925525 | 1050.437328835 | 1044.7039465612 | 1078.4720676713 | 1075.9866712751 | 1052.9266207215 | 1059.6547379255
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

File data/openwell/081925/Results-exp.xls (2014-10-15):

 | Area | Mean | Min | Max
1 | 3234 | 403.843 | 356 | 473
2 | 3234 | 404.224 | 367 | 480
3 | 3234 | 403.439 | 362 | 458
4 | 3234 | 403.541 | 351 | 458
5 | 3234 | 403.267 | 364 | 463
6 | 3234 | 403.564 | 366 | 473
7 | 3234 | 403.442 | 359 | 473
8 | 3234 | 403.705 | 365 | 461
9 | 3234 | 403.229 | 369 | 473
10 | 3234 | 402.840 | 358 | 459
11 | 3234 | 402.969 | 360 | 464
12 | 3234 | 402.744 | 366 | 469
13 | 3234 | 403.012 | 351 | 459
14 | 3234 | 405.916 | 368 | 481
15 | 3234 | 421.059 | 379 | 486
16 | 3234 | 442.418 | 402 | 512
17 | 3234 | 466.788 | 423 | 552
18 | 3234 | 496.147 | 449 | 597
19 | 3234 | 530.956 | 482 | 623
20 | 3234 | 559.383 | 513 | 649
21 | 3234 | 584.185 | 529 | 675
22 | 3234 | 607.185 | 558 | 699
23 | 3234 | 629.400 | 562 | 732
24 | 3234 | 650.291 | 595 | 760
25 | 3234 | 667.333 | 612 | 761
26 | 3234 | 682.008 | 617 | 788
27 | 3234 | 692.698 | 642 | 800
28 | 3234 | 703.232 | 651 | 829
29 | 3234 | 711.126 | 662 | 841
30 | 3234 | 718.392 | 668 | 829
31 | 3234 | 725.138 | 655 | 829
32 | 3234 | 730.999 | 676 | 875
33 | 3234 | 736.835 | 683 | 866
34 | 3234 | 741.917 | 683 | 861
35 | 3234 | 746.774 | 688 | 856
36 | 3234 | 750.669 | 695 | 864
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

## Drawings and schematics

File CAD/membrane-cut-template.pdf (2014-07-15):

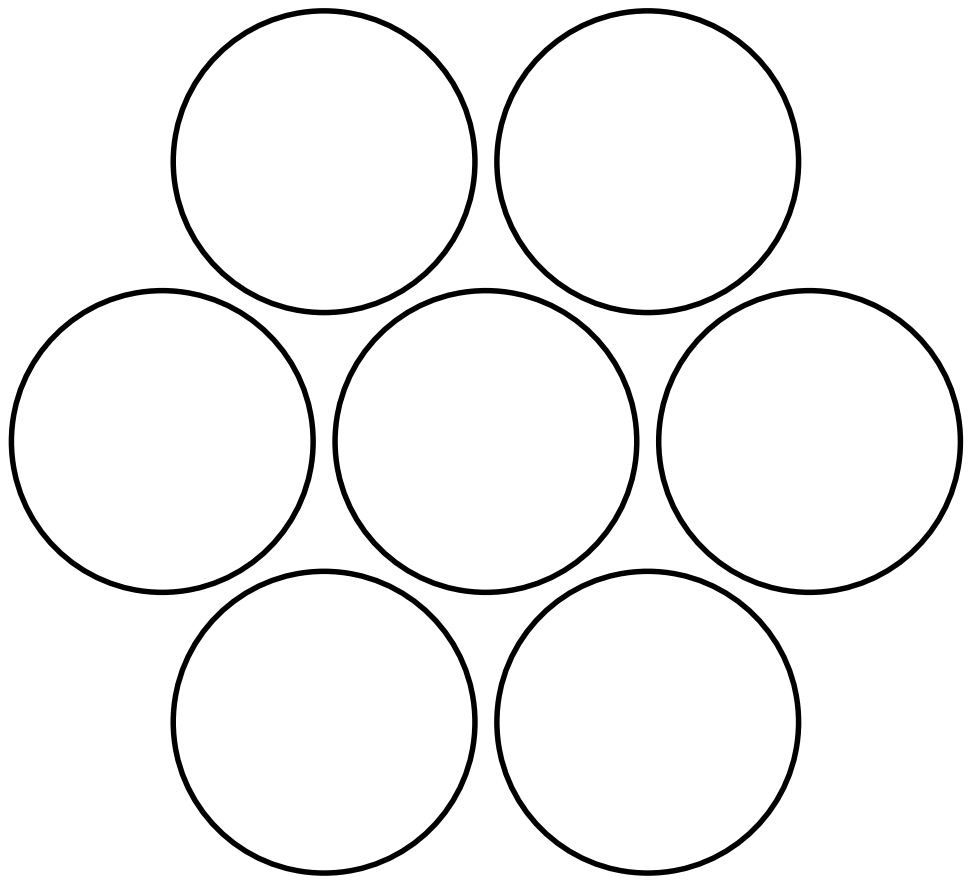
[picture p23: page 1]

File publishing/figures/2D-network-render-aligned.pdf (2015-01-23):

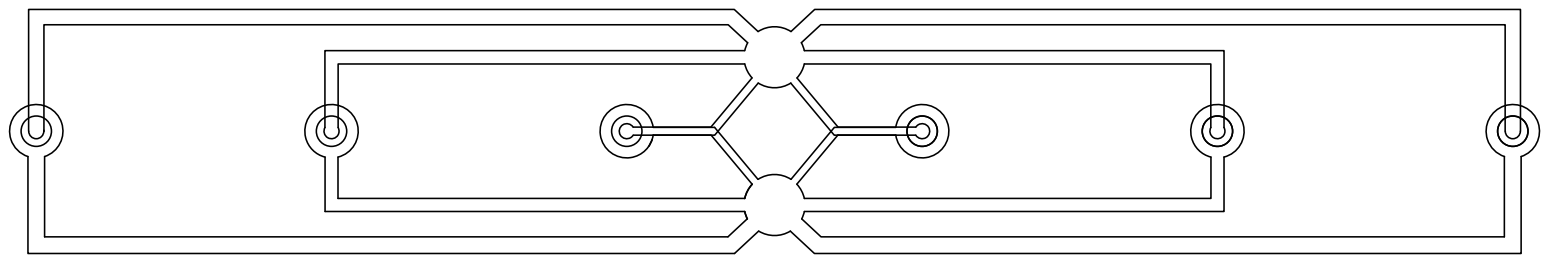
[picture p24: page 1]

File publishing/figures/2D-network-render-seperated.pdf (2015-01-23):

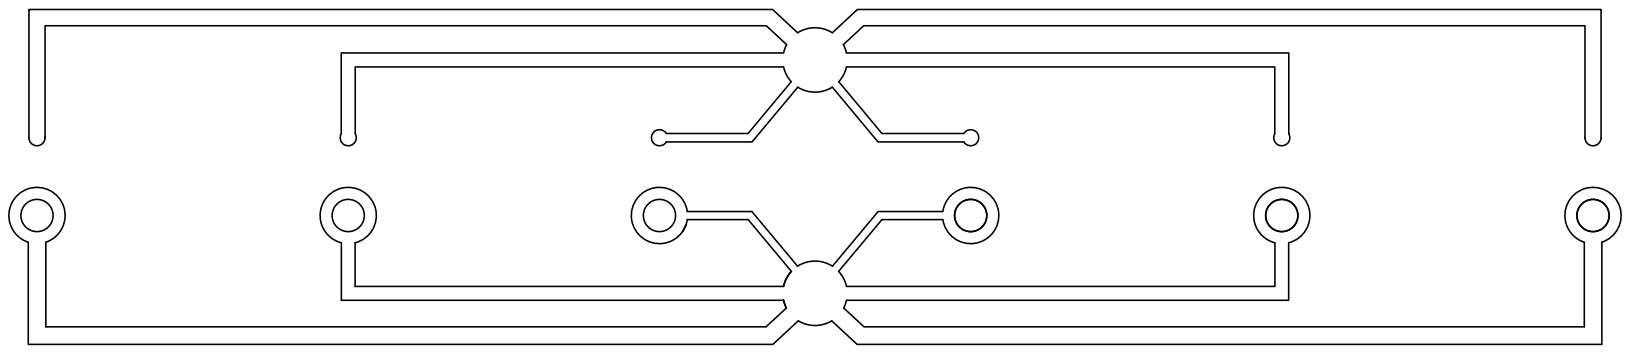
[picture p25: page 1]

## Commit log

2014-05-13 added sternvolmer.m and re-organized data in to folders by date
    [intensities050714-spreadsheet.ods]
2014-05-13 cleaned up folder, added to gitignore
    [well1.csv]
2014-05-20 changed file name that data is loaded from and made comments
    [intensities.csv]
2014-05-20 started data for 050814
    [intensities.csv, intensities050814-spreadsheet.ods]
2014-06-04 added calibration averages and made into new sheet
2014-06-04 analyzed 050914 data and added comment to sternvolmer6.m
    [intensities.csv]
2014-06-04 finished analyzing data for 3 days added a temp template file
    [intensities.csv]
2014-07-01 added 6 well insert design in blend and stl
    [6-well-insert.blend, 6-well-insert.stl]
2014-07-01 starting 6 well from 6 well insert
    [6-well.blend]
2014-07-01 added 24 well plate dimensions
    [24-well-plate-dimensions.csv]
2014-07-01 extended pillars to reach of 17.35
    [24-well-plate-dimensions.csv, 6-well.blend]
2014-07-01 fixed non-manifold inlets
    [6-well.blend]
2014-07-01 exported new stl
    [6-well-insert.stl]
2014-07-01 added 6 well stl
    [6-well.stl]
2014-07-03 updated dim spreadsheet
    [24-well-plate-dimensions.csv]
2014-07-03 added new radius edges
    [6-well.blend]
2014-07-03 deleted outside pillar faces
    [6-well.blend]
2014-07-03 adding faces
    [6-well.blend]
2014-07-03 faces to be deleted for supports selected
    [6-well.blend]
2014-07-03 supports added
    [6-well.blend]
2014-07-03 starting adding micro pillars
    [6-well.blend]
2014-07-03 ready to face around microposts
    [6-well.blend]
2014-07-03 deleted duplicates and faced between microposts
    [6-well.blend]
2014-07-03 starting faces around post
    [6-well.blend]
2014-07-03 expanded pillar bottom completed
    [6-well.blend]
2014-07-03 cut and duplicated to all 6 pillars
2014-07-03 exported stl
2014-07-10 added membrane cutting template
    [membrane-cut-template.dwg]
2014-07-15 added printable membrane template
2014-09-16 extented outer walls 3 mm each
2014-09-16 24 well device ready for export
2014-09-16 exported 23-well.stl
2014-10-09 added new data
    [intensites.csv]
2014-10-09 analyzed data and made new plot
    [intensities.csv]
2014-10-15 added open well data
    [Results-exp.xls, Results.xls, cals.xls]
2014-10-15 added 100414 intensites.xls
    [intensites.xls]
2014-10-16 added new data and stated plotting
    [intensities.csv]
2014-10-20 added old cad files
    [barb.stl, multiembryo.stl]
2014-10-20 added old figures and cad files
    [2D-network.dwg, 2d-distro-template.dwg]
2014-11-13 added open well device
    [open-well-petri.blend]
2014-11-13 added stl of petri-dish and started well render
    [24-well-render-well.blend, open-well-petri.stl]
2014-11-14 isolated centered pillar
    [24-well-render-well.blend]
2014-11-16 parts ready to cross section
    [24-well-render-well.blend]
2014-11-16 ready to face well
    [24-well-render-well.blend]
2014-11-16 cut well and membrane
    [24-well-render-well.blend]
2014-11-18 faced top
    [24-well-render-well.blend]
2014-11-18 started manual slice of pillar
    [24-well-render-well.blend]
2014-11-19 cross section of pillar done
    [24-well-render-well.blend]
2014-11-19 ready to render
    [24-well-render-well.blend]
2014-12-04 added render and screenshot
    [pillar-well.blend]
2014-12-10 new 24 well data set
    [intensities.csv]
2014-12-31 working on 24 well stern
    [intensities.csv]
2015-01-02 stern24 now exports matrix a only
    [evaluated.csv]
2015-01-02 working on plottin
    [evaluated.csv]
2015-01-16 added photos of device
2015-01-23 organized publishing folder, added dist network rendering
    [2D-network-render-aligned.dwg, 2D-network-render-seperated.dwg, 2D-network-render.dwg]
2015-01-23 organized and started distribution network render
    [pillar-well.blend]
2015-01-23 added camera
2015-01-24 updated renderings
    [pillar-well.blend]
2015-01-25 working on figure1
    [pillar-well.blend]
2015-01-25 added 2D schematic to figure1
2015-01-26 added figure 2
    [pillar-well.blend]
2015-01-29 started render for whole device
